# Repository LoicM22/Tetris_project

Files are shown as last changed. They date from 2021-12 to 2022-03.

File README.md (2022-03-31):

# Tetris_project

The goal of this project was to create a wireless controller to a Tetris game which is coding in Python. 
All the steps for the creation of this project are detailed on "final_notice_tetris_project.pdf".

# Details of each folder

This repository is divided in 5 parts :

  - Assembly_of_the_controller : the assembly instructions and all the drawings of the parts of the controller
  - How_to_play : details of the movements of the game in fr and eng
  - PCB : Kicad files of the PCB made for the LED of the controller
  - Prog_Rasp : The code to put in the Raspberry and the instructions
  - Prog_Arduino : The code to put in the Arduino and tests for the state machine

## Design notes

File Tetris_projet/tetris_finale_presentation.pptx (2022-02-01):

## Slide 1

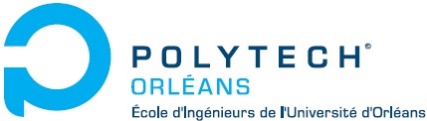
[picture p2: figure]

Project S10: Tetris project
24/01/2022

Student of Project:
MARCHAND Loïc

Tutor of Project:
WEBER Rodolphe

## Context

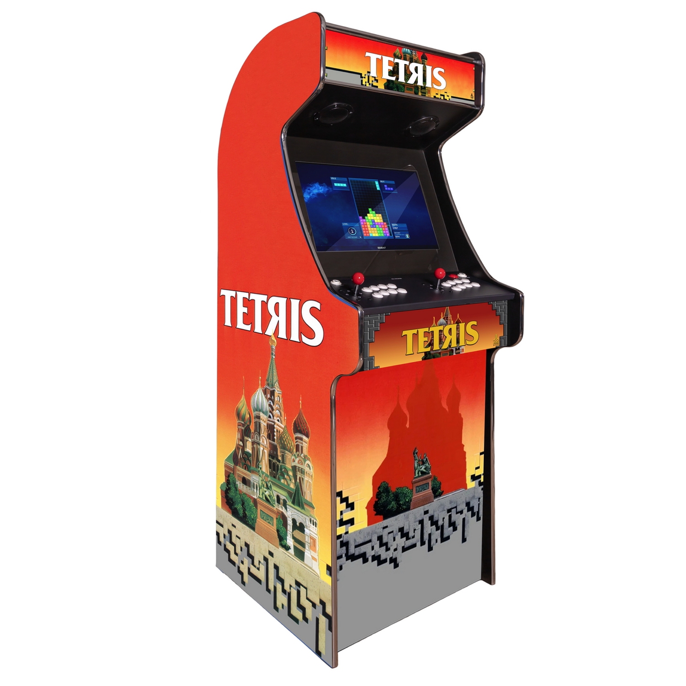
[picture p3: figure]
Borne Arcade Tetris – EZ Borne Arcade – le spécialiste de la borne arcade.
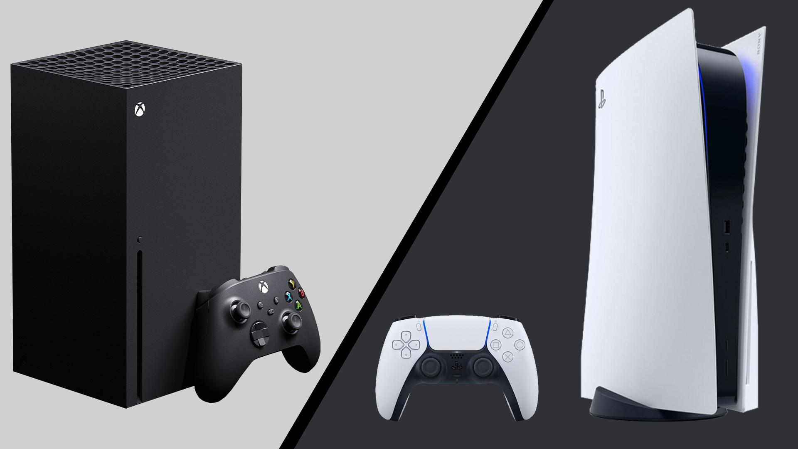
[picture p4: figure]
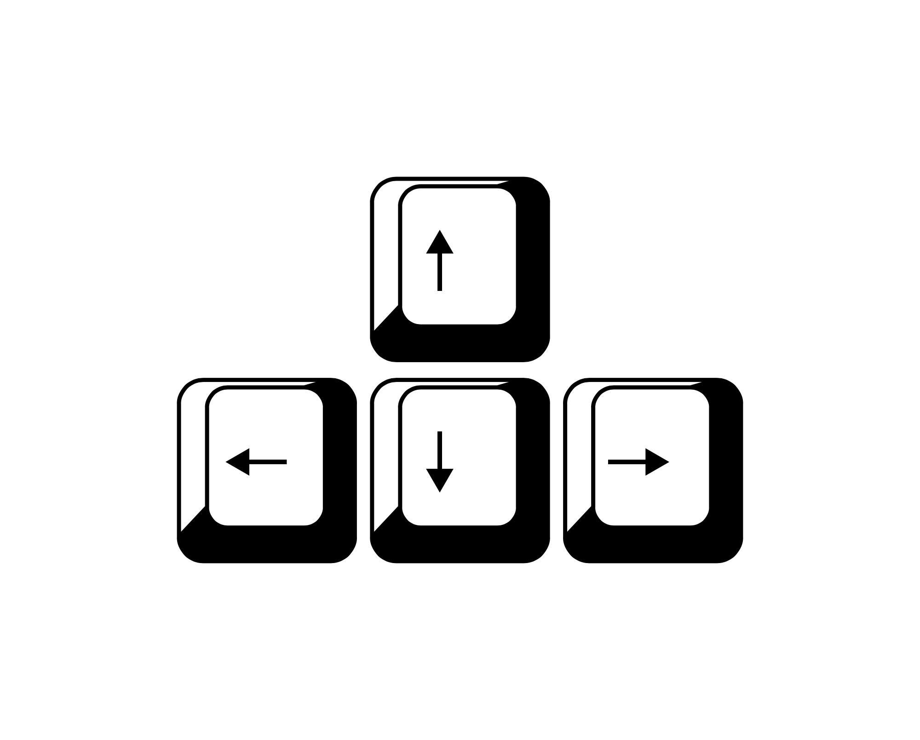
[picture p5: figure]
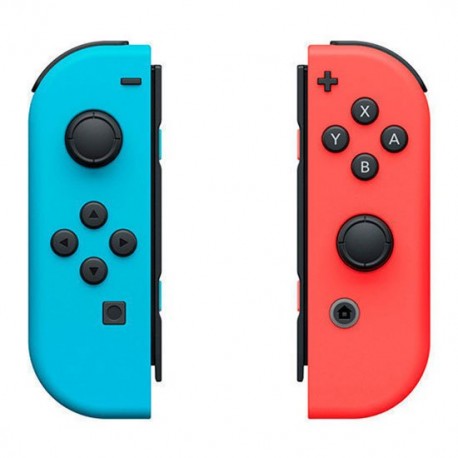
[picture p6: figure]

Loïc Marchand
5A GPSE

## Context

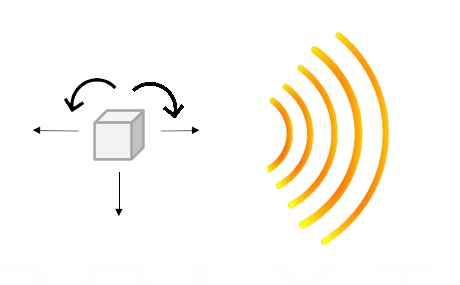
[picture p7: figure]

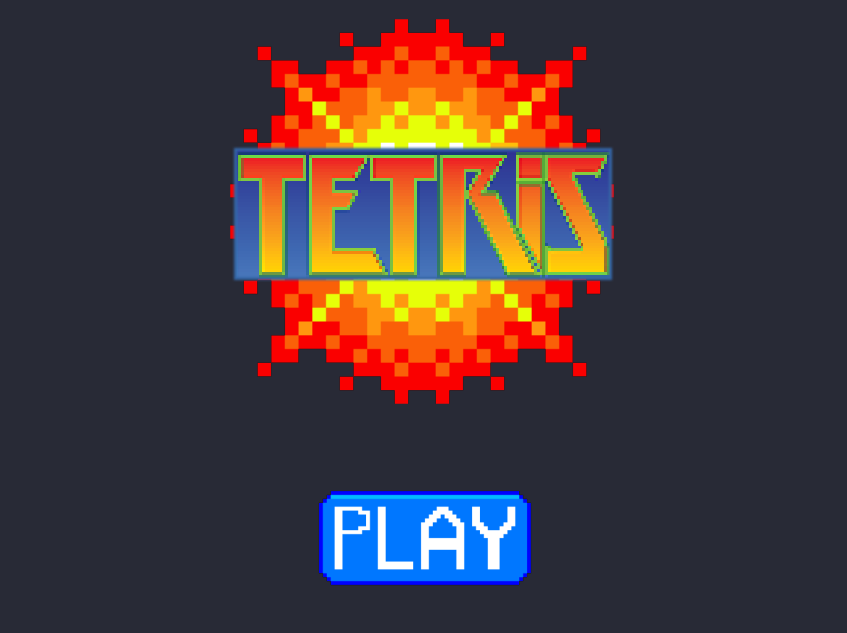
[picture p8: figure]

Loïc Marchand
5A GPSE

## Objectives

Playable by a child :
Operating time : > 1h
Operating distance : ~ 2m
Response time : < 250ms

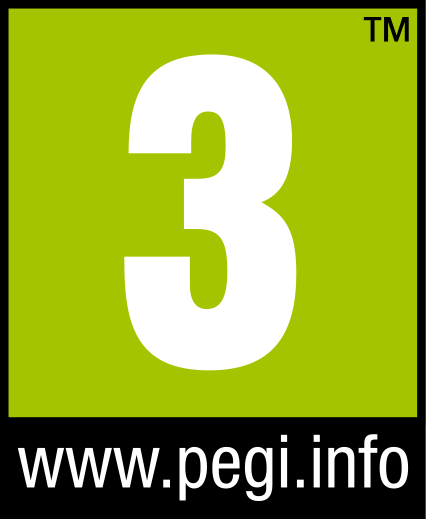
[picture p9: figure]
PEGI

Weight of the controller : < 500g
Reload time of the controller : < 30 min
Size of the controller : 7x7x7 cm
Power Supply of arcade terminal : 230V

Loïc Marchand
5A GPSE

## Global operation

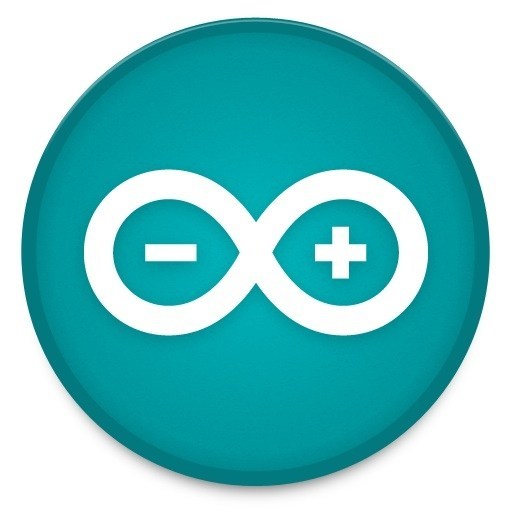
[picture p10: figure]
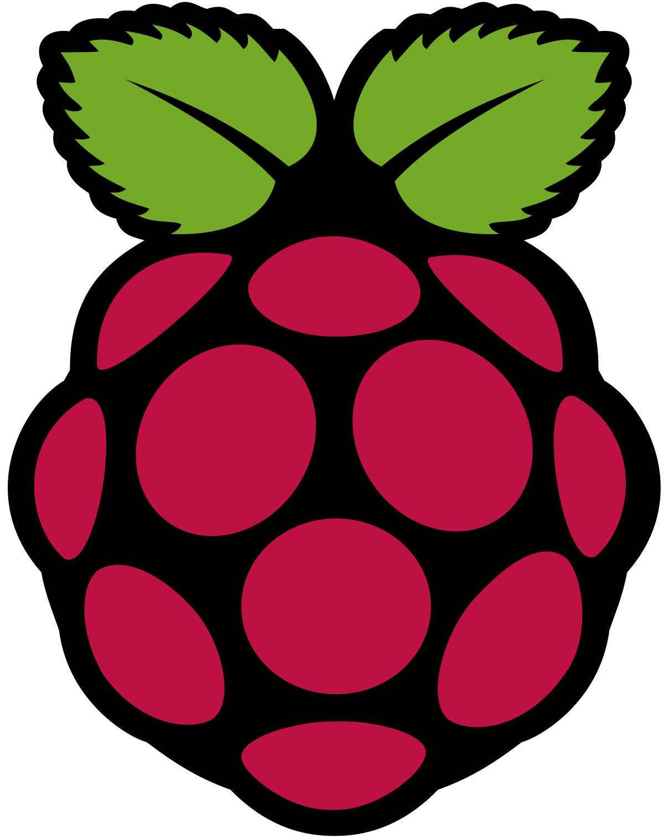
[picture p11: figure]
Raspberry Pi — Wikipédia

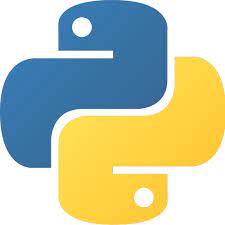
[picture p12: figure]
Pygame Logo - LogoDix

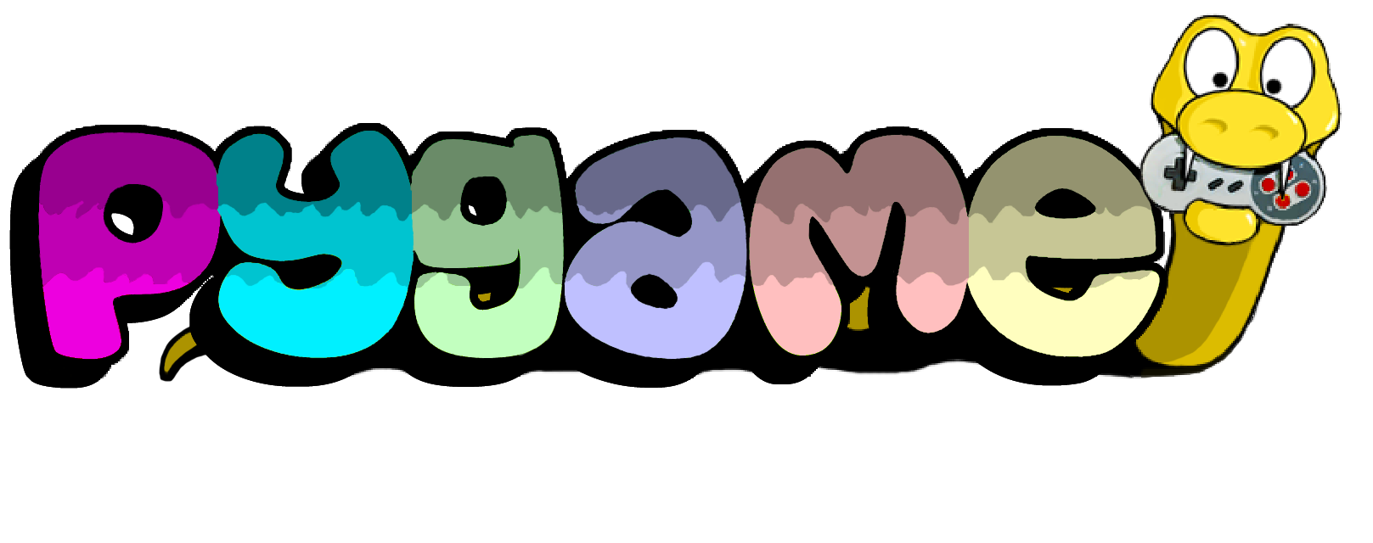
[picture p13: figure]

Arduino Nano Every
AVR ATMega 4809

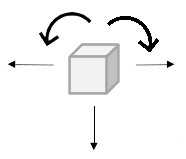
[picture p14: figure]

Serial communication : Rx / Tx

Raspberry Pi 3B+

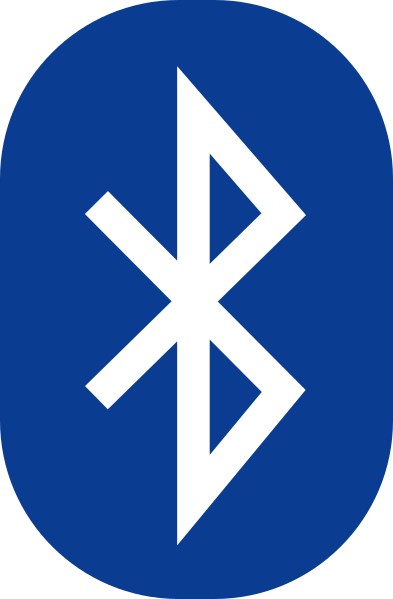
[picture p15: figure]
Fichier:Bluetooth.svg

Loïc Marchand
5A GPSE

## The controller

The design

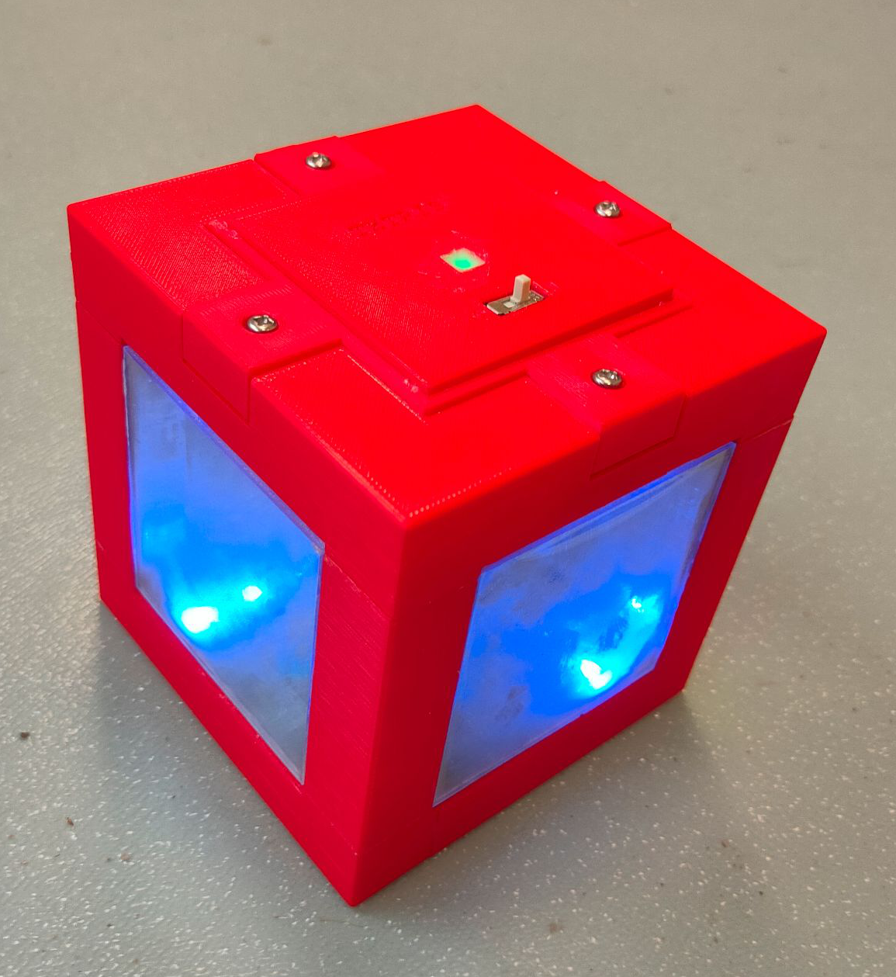
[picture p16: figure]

Size : 10 x 10 x 10 cm
Weight : 373 g
Number of LEDs : 61 LEDs

Loïc Marchand
5A GPSE

## The controller

The electronic part

LED power SJ-10060-2811
+
Power switch

Battery
9V

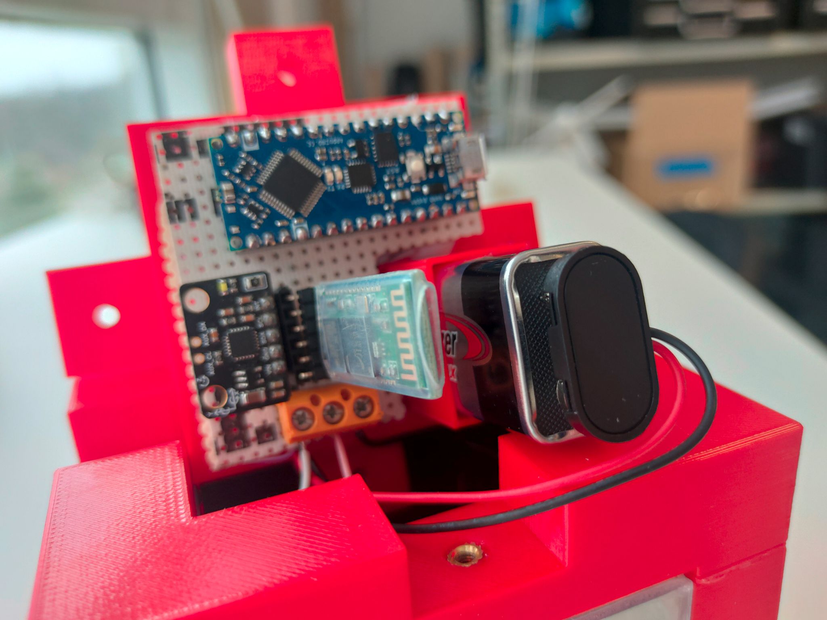
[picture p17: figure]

(3h of autonomy)

Analogic

FastLED / leds[i]

AVR ATMega4809

MPU-6050

LED strip iPixel
SJ-10060-2811

FastLED / leds[i]

I2C

Rx/Tx

HC-05

Serial

(10 meters of
operating
distance)

Loïc Marchand
5A GPSE

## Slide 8

The arcade terminal

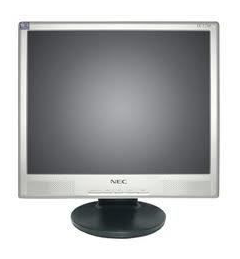
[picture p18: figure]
Nec Ecran LC17M 17&quot; 700P - LaptopService

Screen NEC lc17m (17 inches)

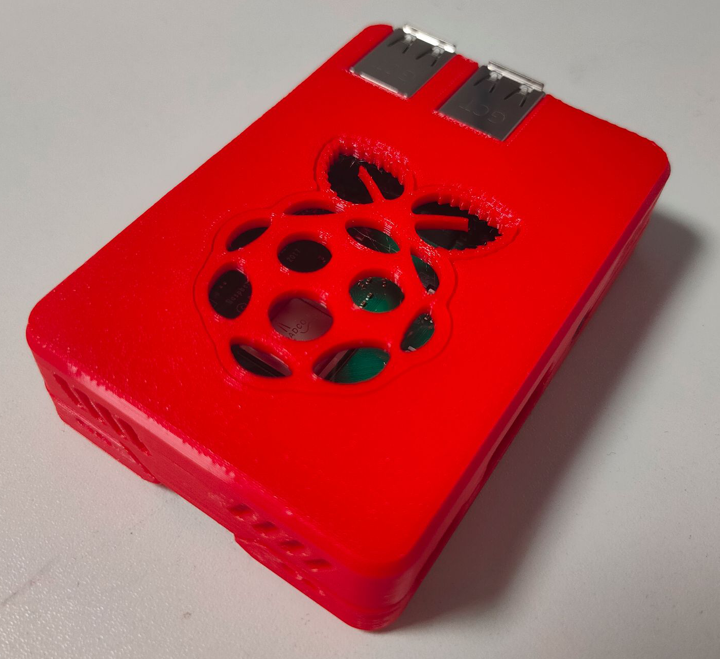
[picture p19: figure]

Raspberry Pi 3B+

Loïc Marchand
5A GPSE

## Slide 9

The arcade terminal

Raspberry part

‘s’

‘w’

‘g’

‘j’

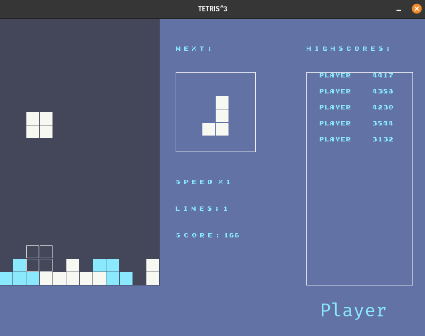
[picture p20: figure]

(Inspired by “farhan” Tetris program)

‘h’

Received by the Raspberry :

- g = b’left\r\n’
- j = b’right\r\n’
- h = b’down\r\n’
- s = b’rotleft\r\n’
- w = b’rotright\r\n’

Loïc Marchand
5A GPSE

## Skills developed

The controller | The arcade terminal
SolidWorks | Pygame : the Python library
The bluetooth of the HC-05 | The bluetooth of the Raspberry
State machine | Python
C language
Kicad

Loïc Marchand
5A GPSE

## Budget

Controller | | Arcade terminal
Components | Price | Components | Price
Arduino Nano Every | 11,35 € (RS Component) | Screen (NEC LC17m) | 89,95 € (Amazon)
HC-05 | 14,50 € (Go Tronic) | Raspberry 3B+ | 28,56 € (RS Component)
MPU6050 | 10,50 € (Go Tronic) | SD card (16Go) | 8,44 € (RS Component)
Battery 9V / 6LR61 | 3,62 € (Conrad)
LED strip (iPixel SJ-10060-2811) | 6,25 € /m (60 LEDs/m) (Alibaba)
PLA (173,09 g) | 18,20 € (filament bobbin of 750 g) (Smart Material 3D)
Power switch | 1,10 € (RS Component)
Resistances (2*330Ω/100kΩ/220kΩ) | 4 * 0,038 € (RS Component)

Time spent : 336 h

Total components : 198,88 €

Loïc Marchand
5A GPSE

## Improvements

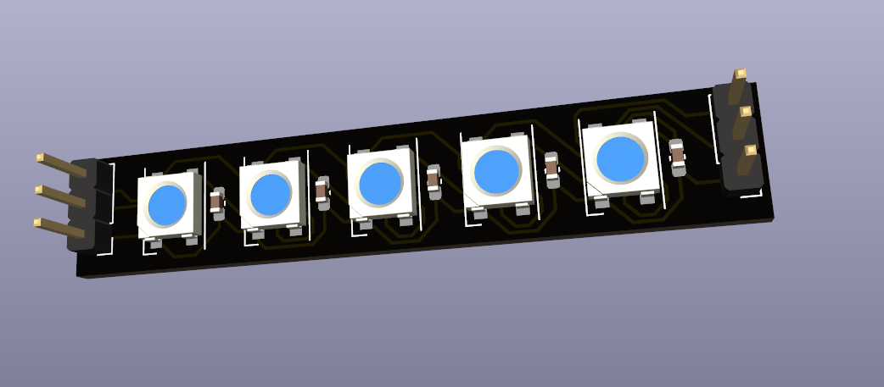
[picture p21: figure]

- Create two PCBs :
  - ~~LEDs~~
  - Controller
- Consolidate the controller to be shock resistant and waterproof
- Add another game (PacMan) with a menu to choose the game we want
- Create the box of the arcade terminal with interactive light

Loïc Marchand
5A GPSE

## Conclusion

Loïc Marchand
5A GPSE

## https://github.com/LoicM22/Tetris_project.git

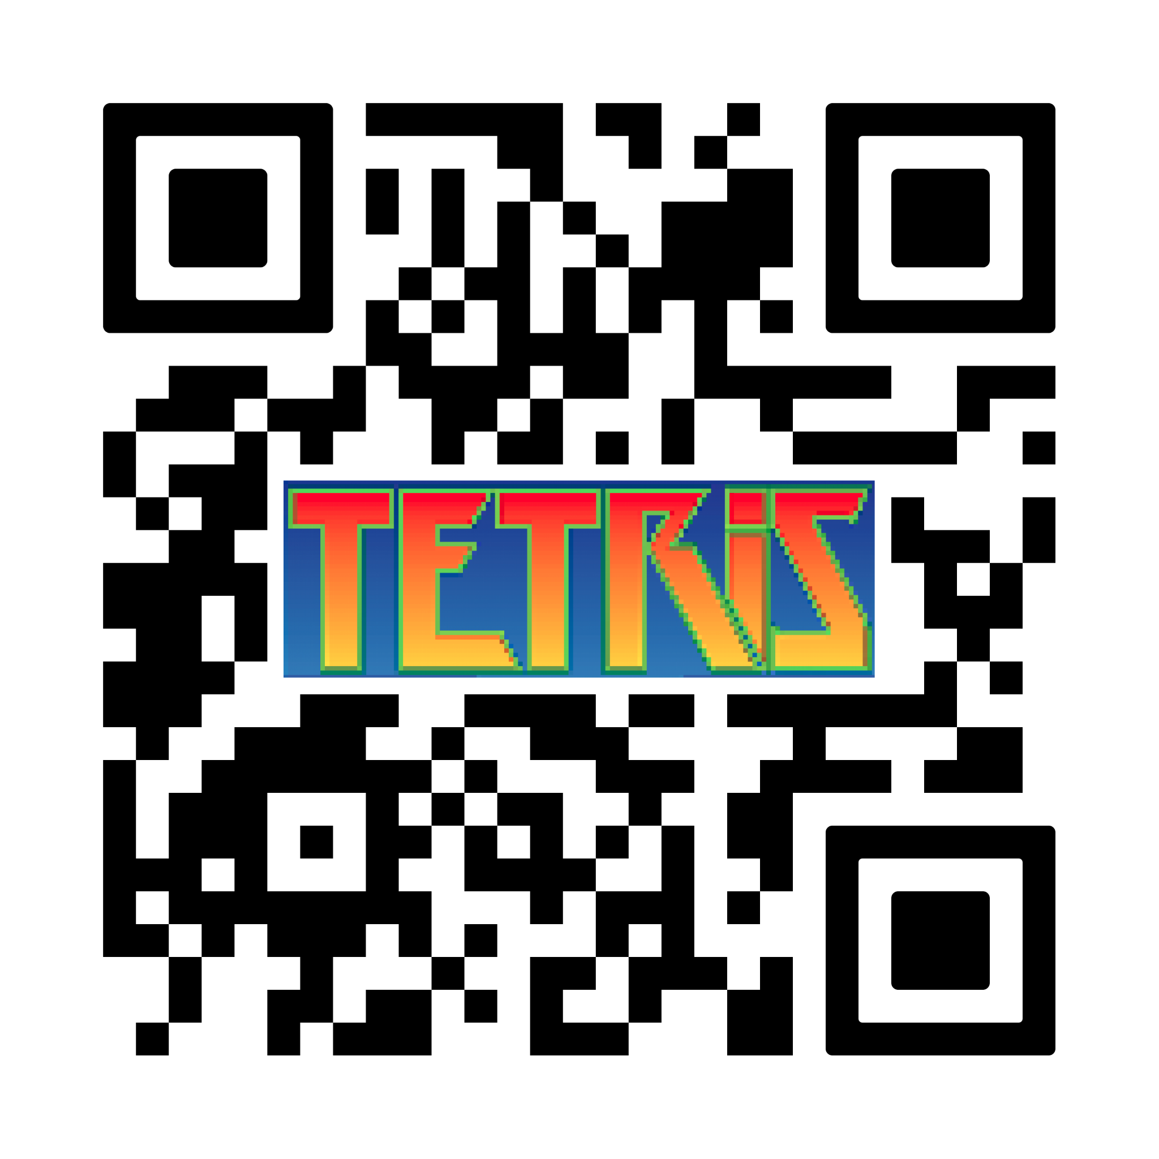
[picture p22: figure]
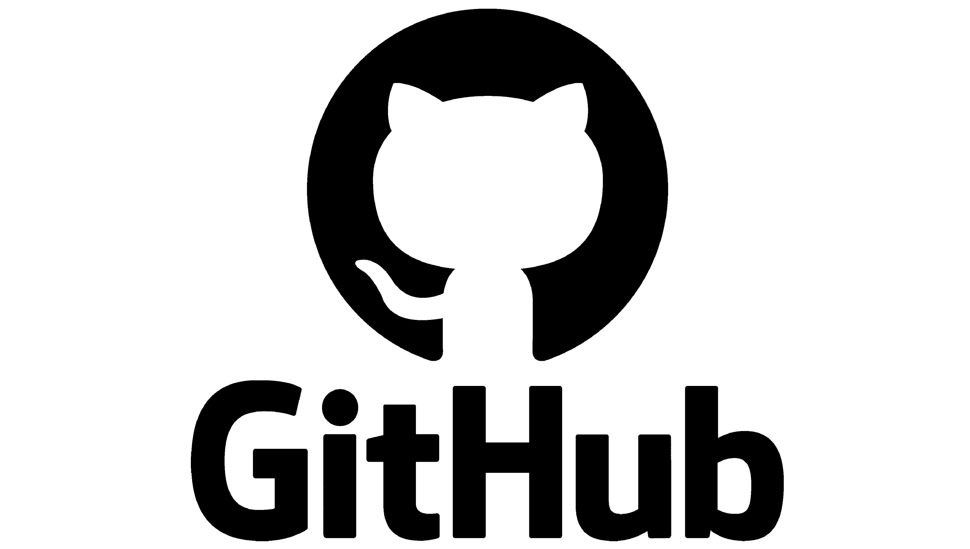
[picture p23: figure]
GitHub Logo - Marques et logos: histoire et signification | PNG

Loïc Marchand
5A GPSE

## Demonstration

Loïc Marchand
5A GPSE

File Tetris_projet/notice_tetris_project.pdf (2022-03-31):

# Notice

# Project Tetris : TETRIS³

## Tutor of the project :

Mr. WEBER Rodolphe (Polytech)

# Contents

Contents | 1
1 Abstract | 3
2 Introduction | 4
3 The controller | 8
4 The arcade terminal | 20
5 Conclusion | 25

1

Polytech Orléans | Notice | 2021 / 2022
List of Figures | 26
A Appendix of the controller | 28
B Appendix of the arcade terminal | 38
Loïc Marchand | Tetris³ | 2

# 1.Abstract

The main subject of this project is to create a new way to play a Tetris game. Indeed,

currently everybody who plays a Tetris game uses a joystick or a keyboard with arrow to

interact with the game.

So, the goal of this project is to be able to play Tetris while using a remote control

that would be inclined or moved (to the right or left) according to how we want to interact

the Tetris block.

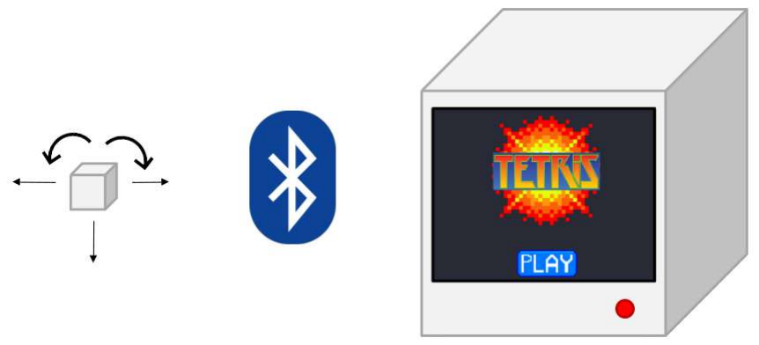
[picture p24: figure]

Figure 1.1: Diagram of the project

# 2.Introduction

## 2.1 Context

Nowadays, the world of gaming is constantly evolving. More and more games are im-

proved to become more like the real life (haptic devices, photorealism, ...).

Nevertheless, the old games like Pac Man, Space Invaders or Tetris attract always the

generation which has grow up.

To make new gamers want to play the old games, some people create a new version of

these games. The gameplay will never change a lot but sometimes the look or maybe a

new mode.

It is with this idea that this project has been designed.

Indeed, with Tetris³, the game doesn’t change but it’s a new way to play to this famous

game.

More technically, this new way is resumed by the control of Tetris with a little cube

connected with Bluetooth to a Raspberry linked to a screen and play a Tetris game.

The little cube is like a wiimote for the Nintendo console. To move the Tetris block on

the screen on the right, the little cube has to be moved on the right too (it’s the same

way with all the other movements).

## 2.2 The project’s goals

In order to define the project and to see more clearly the final objective, a global diagram

has been established :

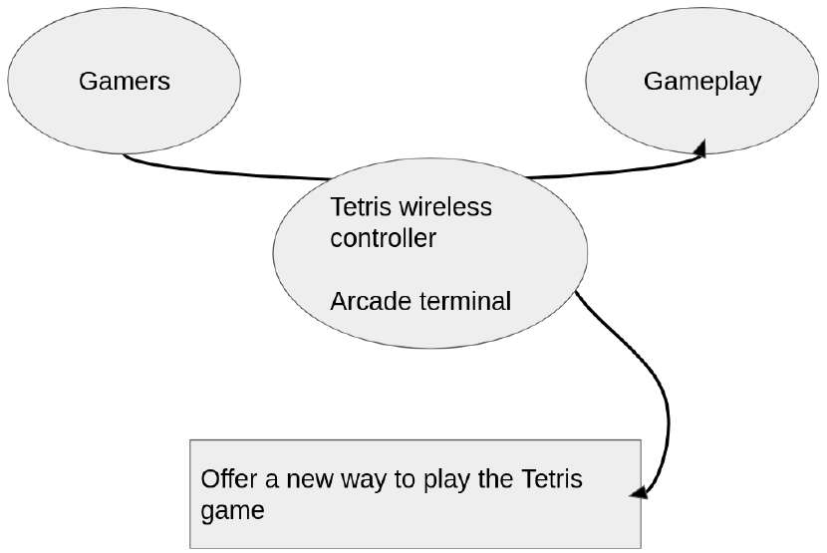
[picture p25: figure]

Figure 2.1: Header beast diagram

After defined the bases of the project, the use functions have to be listed with their

constraints :

Id | Functions | Details | Criteria | Solutions
FP1 | User can play Tetris
FP1.1 | | A user-friendly interface | Usable by a 3 years old chil-dren

FP2 | Having a cube that allows the Tetris to be con-trolled remotely by movements
FP2.1 | | Wireless control cube | Lenght : 2 m | Bluetooth
FP2.2 | | Rechargeable | Time of use : 1h Recharge time : 30min
FP2.3 | | Easy to use | Usable by a 3 years old chil-dren
FP2.4 | | Be fall resistant | Height : 2m
FP2.5 | | Visually attrac-tive | | LED and mirrors
FP3 | Play Tetris on an arcade termi-nal
FP3.1 | | Good quality | | Screen : 17 inches
FP3.2 | | Interact with the game | Lighting effect

FC1 | Be intuitive | Simple control
FC2 | Python program must be flexible | Possibility to put all of the instructions we want
FC3 | Arcade machine works with main power | 230V
FC4 | Good quality of video an sounds | Screen and speakers
FC5 | Be ergonomic | Weight < 500g

The global operation of the project looks like the following diagram :


Figure 2.2: Diagram of the global operation

To resume, the goal of the project is to realise a wireless controller which permit to

control a Tetris on an arcade terminal with the movement of the gamer.

So, in the first instance, the creation and the programming of the controller will be

exposed.

After that, the design of the arcade terminal will be explain.

# 3.The controller

## 3.1 The design

### 3.1.1 The modelling

So, the appearance of the controller is a cube of 10x10x10cm (indeed, the 7x7x7cm wasn’t

enough to put all the light system and the electronic part inside the cube).


Figure 3.1: Photo of the controller

The cube was printed with 3D printer and is composed by PLA (173,09g). It is divided

in nine parts (two for the base of the cube, four for the poles and three for the roof).


### 3.1.2 The wire management

All of these pieces were made with SolidWorks (CAO software) :

Figure 3.2: Model of the tops of the controller

Figure 3.3: Model of the posts of the controller


Figure 3.4: Model of the bases of the controller

The assembly instructions and the drawings of all the pieces of the controller are

detailed on the appendix A.

### 3.1.3 The light effect

The light effect on each face is an infinite effect.

The necessary equipment to create this infinite effect is one mirror, one half reflecting

glass and obviously some LEDs. If these LEDs are positioned between the mirror and the

half reflect, all the light will be reflected on the mirror but that will not be the same case

for the half reflect glass. It let pass only the half light and reflect the other half and it’s

this phenomenon which create the infinite effect.

## 3.2 The electronic part

Figure 3.5: Photo of the electronic part

The electronic part inside the cube is divided in four parts. All of these parts are con-

trolled by an Arduino Nano Every which is composed by an AVR ATMega 4809 (the

microcontroller). This type of board was chosen for its simplicity of programming.


Figure 3.6: Schematic of the electronic part

A more detailed schematic of the electronic part can be found in appendix A.10.

### 3.2.1 The LED strip


Figure 3.7: Schematic of the LED strip part

In this part, there is the LED strip (composed by 60 RGB LEDs), one resistance of

330ohm and the Arduino. The LED strip has 3 pins, one for the 5V, one for the ground

and a last one to program the LED strip. Indeed, this LED strip is addressable so it’s

possible to choose which LED will turn on and with which color by using FastLED (it’s

an Arduino librairy which works with this LED strip). To not damage the LED strip,

one resistant must be connect between the pin of the Arduino and the pin which permit

to program the LED strip.

To create a movement of rotation with the LED on every face of the cube, it’s neces-

sarily to make a loop between 12 LEDs and at each "i" loop, the LED "i-1" is turned off

and the LED "i" is turned on. When the loop was made 12 times, the patern is restarted.

### 3.2.2 The battery


Figure 3.8: Schematic of the battery part

The controller (so the Arduino) is powered by a 9V battery. To find out how much

battery is left before the Arduino is under powered, it’s useful to create a tension divider

bridge and connect it to one analogic pin to the Arduino. Indeed, the analogic pins of the

Arduino Nano Every can support only 5V but no more.


Figure 3.9: Schematic of the tension dividing bridge

After that, with a program which calculates the pourcentage of the battery on the

Arduino and with the use of one new RGB LED, the user will know how much time the

controller will continue to be powered. This LED will be blue if the pourcentage of the

battery is between 100% and 80%, green between 80% and 60%, yellow between 60% and

40%, orange between 40% and 20%, and finally red under 20%.

### 3.2.3 The MPU6050


Figure 3.10: Schematic of the MPU6050 part

The MPU6050 is a component with an accelerometer 3 axis and a gyroscope 3 axis.

The accelerometer will be reserved for the translation movements of the tetris block

and the gyroscope for the rotation.

But, without adjustment, the accelerometer and the gyroscope can’t be used.

### 3.2.3.1 The accelerometer


Figure 3.11: Graphic of the evolution of acceleration on Y axis

In fact, for example with the accelerometer with the Y axis on the figure 3.9, the blue

curve represents the variation of the value of the Y axis sensor for the acceleration during

175 seconds. It’s a test made with a Python program to observe how the acceleration

evolve during a movement. When the sensor is moved on the direction of positive Y there

is a rise in value and immediately after a fall until reaching the opposite value and the

returning to a value close to zero. This phenomenon is due to the compensation of the

acceleration.

Indeed, when something accelerate and stop very quickly, an opposite acceleration,

due to the compensation, is detected. That create a problem if we want to distinguish a

movement (go to right for example) and its opposite (go to left).

To detect the right movement and to prevent the acceleration compensation, the tech-

nique adopted is the creation of a state machine to analyse every possibility of our signal

and assign the appropriate move when it’s relevant.


Figure 3.12: Schematic of the state machine for the accelerometer

The numbers in red represent all the different states in which the system can be. Sp

and Sn are two thresholds which are been chosen after some tests with the different values

of the accelerometer, Sp is the positive threshold and Sn is the negative one.

To explain this state machine, as long as the value of the accelerometer doesn’t surpass

Sp or Sn, there isn’t movement detected. As soon as the threshold is exceeded by the value, the instruction of the movement is sent at the state 1 or 3 (for example, with the

X axis, when Sp is exceeded the program sends "right", and "left" if it’s Sn). As long as

the value is superior (for Sp) or lower (for Sn), there isn’t movement sends.

The state 2 and 4 are made to avoid the acceleration compensation. Indeed, for

positive value, while it doesn’t surpass Sn, the program stays in the state 2 and send

nothing. That is the same with negative value, while it doesn’t be lower than Sp the

program stays in the state 4. The result is observable with the orange curve one the

Figure 3.9.

In this project, this state machine will be mainly used for the "left" and "right"

movements (on the X axis) and for the "down" movement (on the Z axis).

### 3.2.3.2 The gyroscope

Another problem appears with the gyroscope.


Figure 3.13: Graphic of the evolution of gyroscope on X axis

Indeed, when the controller is turned in one direction (left or right), everytime the

program on the Arduino makes a loop and as long as the position of the controller is

not changed, an instruction of movement is sent (blue curve on Figure 3.11). To have a

playable game, the gyroscope must send the movement only after a change of the position

of the cube.


Figure 3.14: Schematic of the state machine for the gyroscope

In this state machine, four thresholds have been introduced, two for the positive values

and two for the negative values (one for a low threshold and one for a high threshold).

For example with the positive part, as long as the value of the gyroscope doesn’t

surpass Shp (the positive high threshold), nothing will be send and the program stay

on state 0. At the moment of the value exceeds Shp the program pass on state 1, the

instruction of the movement of rotation is sent (here "rotright" for the right rotation)

and directly after the program changes on state 2. While the value is higher than Sbp,

nothing changes and the program stays on state 2. As soon as the signal is lower than

Sbp, the program changes on state 0 only and nothing is sent.

The effect of this state machine is observable one the figure 3.11 with the orange curve.

In the graphic, the Shp is equal to 12000, Shn is equal to -12000, Sbp is equal to 5000 and

Sbn is equal to -5000. These different values are chosen to have a good playing experience

without interfere with the acceleration information as far as possible.

### 3.2.4 The Bluetooth


Figure 3.15: Schematic of the blutooth part

The bluetooth deserves to link the controller (here the Arduino) to send the instruction

of movement with the arcade terminal (here the Raspberry). Every information is sent

with a serial communication. In this project, the information sent by the Arduino are

"left", "right", "down", "rotright" and "rotleft".

The bluetooth is made with a HC-05 which is linked to the Rx/Tx pins of the Arduino.

It’s a good bluetooth module in the case of this project because it’s easy to use, the

consumption of the battery isn’t so high (80mAh), the sending data time is closed to the

real time and the operating is higher than 10 meters.

# 4.The arcade terminal

This part deals with the creation of the arcade terminal. The arcade terminal is composed

by a screen and a Raspberry Pi 3b+.


Figure 4.1: Components of the arcade terminal

As we can see on the figure 4.1, a keyboard and a computer mouse are still necessary

to navigate and use two commands to play Tetris with the controller (the commands are

on the Appendix B.1).

## 4.1 The Tetris game

The Tetris game is a Python program inspired by the Tetris program of farhan on GitHub.

The game is divided in 3 parts.

There is the opening screen :


Figure 4.2: Opening screen of the game

After press the ENTER key, the game is on and a second screen replaces the first one.

It’s the screen where the user plays the game :


Figure 4.3: Screen of the playable game

When the game is over, an new screen appears :


Figure 4.4: Game over screen

To start a new game, the ENTER key has to be pressed again.

This Python program has been chosen because of its simplicity of programming. In

fact, all the game is developed with Pygame library. This library deserves to program

some games (not only Tetris) on Python and it’s a very intuitive library. Thanks to

this library, it’s easy to change the music, the sound and the color of the game (blocks,

interface), the opening and the game over screen, the speed of the game and the score.

The game launch and the bluetooth connection between the controller and the rasp-

berry aren’t automatic, so a keyboard is indispensable to write the appropriate line of

code on the terminal before playing.

## 4.2 The controls

After customize the aspect of the game, the last thing to do is to link the information

send by the Arduino with the commands of the game.

When the Arduino sends an information, the Raspberry receives the following data :

Then, it’s necessary to choose which letter will be associated with which movement.

Figure 4.5: Letters associate with movement

After chosen the letters, to interact on the game with the controller, a second Python

program must be written. This second program will imitate the press of one key on

the keyboard. For example, when the user go right with the controller, the raspberry

will associate the data it receives with the press of the ’j’ key of the keyboard. It will

run during the game in the background and it will begin in the same time the game is

launched.

The Pygame library has always some event which recognize what letter is pressed on

the keyboard. With this functionality, the project could be changed to be adapted to

other old agames (PacMan for example because this game has some simple movements

too).


Figure 4.6: Movements of the game

To make understanding of the controls of the game more intuitive, a document which

specifies all the possible movements of the game is made.

Due to lack of time, the aspect of the arcade terminal isn’t made.

# 5.Conclusion

## 5.1 General conclusion

This project was divided principally in two parts. One part about the creation of a

bluetooth controller and a second part for the assembly of the arcade terminal. For the

first part, even if the gameplay isn’t perfect with the use of the state machines, the criteria

are mostly respected. Maybe the use of the interruption to send just at the right time

the information could be a good option. For the second part, all the technical part is

operational, just the aspect of it isn’t here. For the aspect, it may be interesting to add

some LED which light up at the same time of a particular action on the game.

## 5.2 Personal conclusion

Personally, this project was a very instructive project in terms of technical skills and

project management.

With this project, I have developed my skills on programming with the comprehension

of the Tetris program to adapt it with the project (the colors of Polytech school on

the blocks for example). I discovered the use of the state machine with the different

sensors. By modelling the cube, I learned a lot of things with the use of SolidWorks. The

programming of the Arduino improves my skill on C language and the use of the bluetooth

gives me a better understanding about the communication between 2 electronic boards

(here the Arduino and the Raspberry).

In terms of project management, I upgraded my skills about time and tasks manage-

ment. Indeed, being alone on this project gives me a global vision of each role that an

engineer can have.

# List of Figures

1.1 Diagram of the project | | 3
2.1 Header beast diagram | | 5
2.2 Diagram of the global operation | | 7
3.1 Photo of the controller | | 8
3.2 Model of the tops of the controller | | 9
3.3 Model of the posts of the controller | | 9
3.4 Model of the bases of the controller | 10
3.5 Photo of the electronic part | 11
3.6 Schematic of the electronic part | 11
3.7 Schematic of the LED strip part | 12
3.8 Schematic of the battery part | 13
3.9 Schematic of the tension dividing bridge | 14
3.10 Schematic of the MPU6050 part | 15
3.11 Graphic of the evolution of acceleration on Y axis | 15
3.12 Schematic of the state machine for the accelerometer | 16
3.13 Graphic of the evolution of gyroscope on X axis | 17
3.14 Schematic of the state machine for the gyroscope | 18
3.15 Schematic of the blutooth part | 19
4.1 Components of the arcade terminal | 20
4.2 Opening screen of the game | 21
4.3 Screen of the playable game | 21
4.4 Game over screen | 22
4.5 Letters associate with movement | 23

26

4.6 Movements of the game | 24

# A.Appendix of the controller

## A.1 Assembly instructions


28

## A.2 Drawing of base_1

## A.3 Drawing of base_2

## A.4 Drawing of poteau1

## A.5 Drawing of poteau3

## A.6 Drawing of poteaux24

## A.7 Drawing of toit1

## A.8 Drawing of toit2

## A.9 Drawing of toit3


## A.10 Detailed schematic of the electronic part


# B.Appendix of the arcade terminal

B.1 | Command to launch the game on the Raspberry
B.1.1 | To connect to the HC-05

Turn on the controller

sudo rfcomm connect hci0 98:D3:91:FD:E6:9D 1

(XX:XX:XX:XX:XX:XX code depends on your stuff)

B.1.2 To run the game

cd tetris_bluetooth

run game.py (if it doesn’t work, use : python3 game.py)

## B.2 Github of the project

https://github.com/LoicM22/Tetris_project.git

38

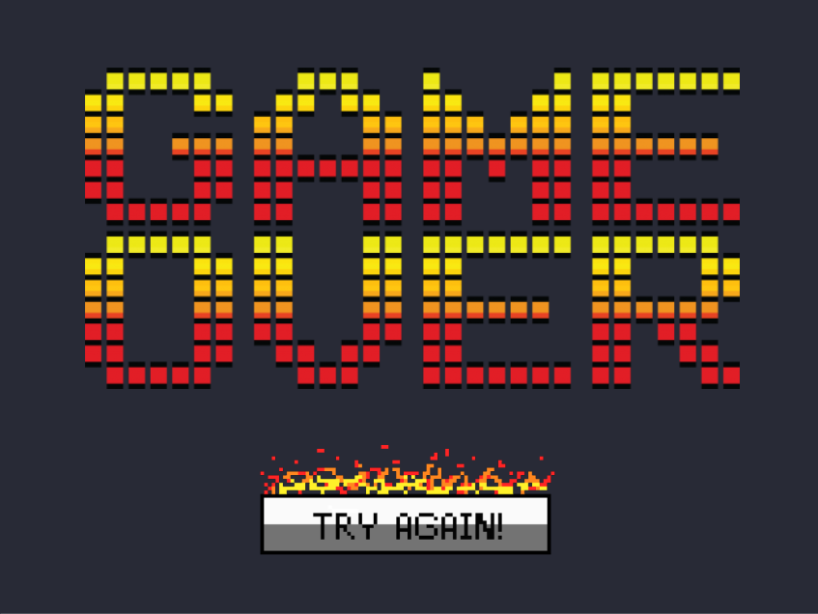
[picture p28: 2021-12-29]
Tetris_projet/Prog_Rasp/tetris_bluetooth/go_screen.png

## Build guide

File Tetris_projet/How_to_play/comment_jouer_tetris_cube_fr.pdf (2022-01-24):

# COMMENT JOUER ?

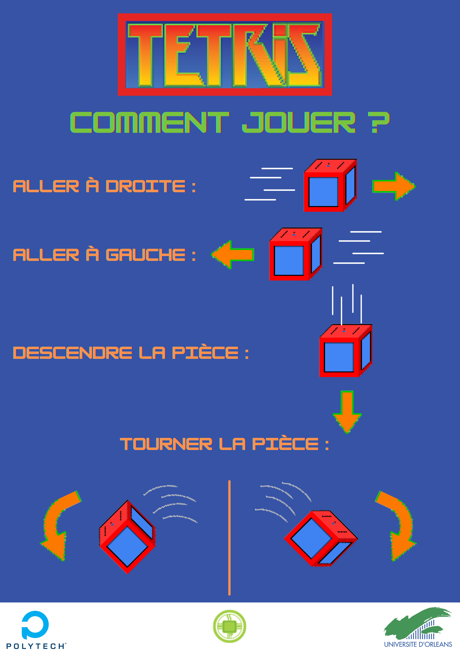
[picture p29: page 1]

TOURNER LA PIÈCE :

ALLER À DROITE :

ALLER À GAUCHE :

DESCENDRE LA PIÈCE :

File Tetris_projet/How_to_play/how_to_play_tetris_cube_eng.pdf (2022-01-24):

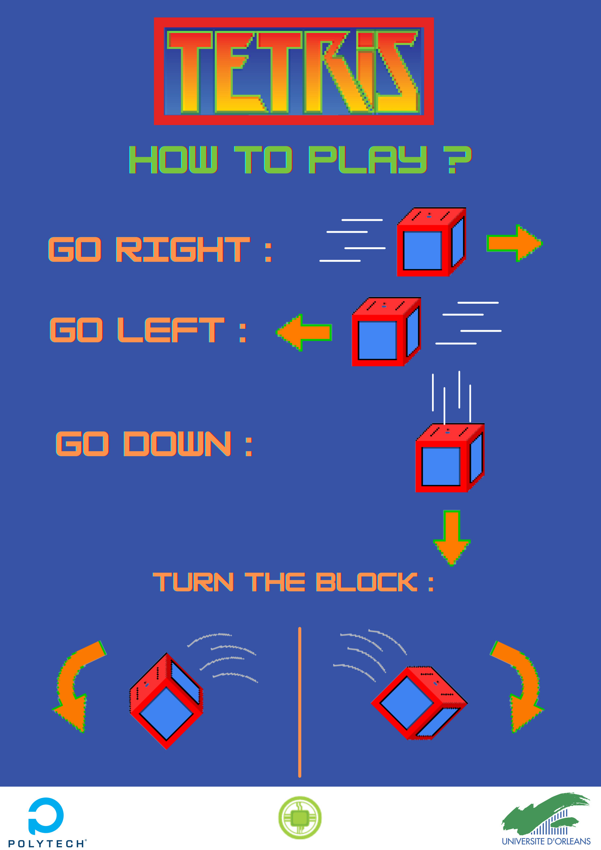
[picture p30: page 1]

TURN THE BLOCK :

HOW TO PLAY ?

GO RIGHT :

GO LEFT :

GO DOWN :

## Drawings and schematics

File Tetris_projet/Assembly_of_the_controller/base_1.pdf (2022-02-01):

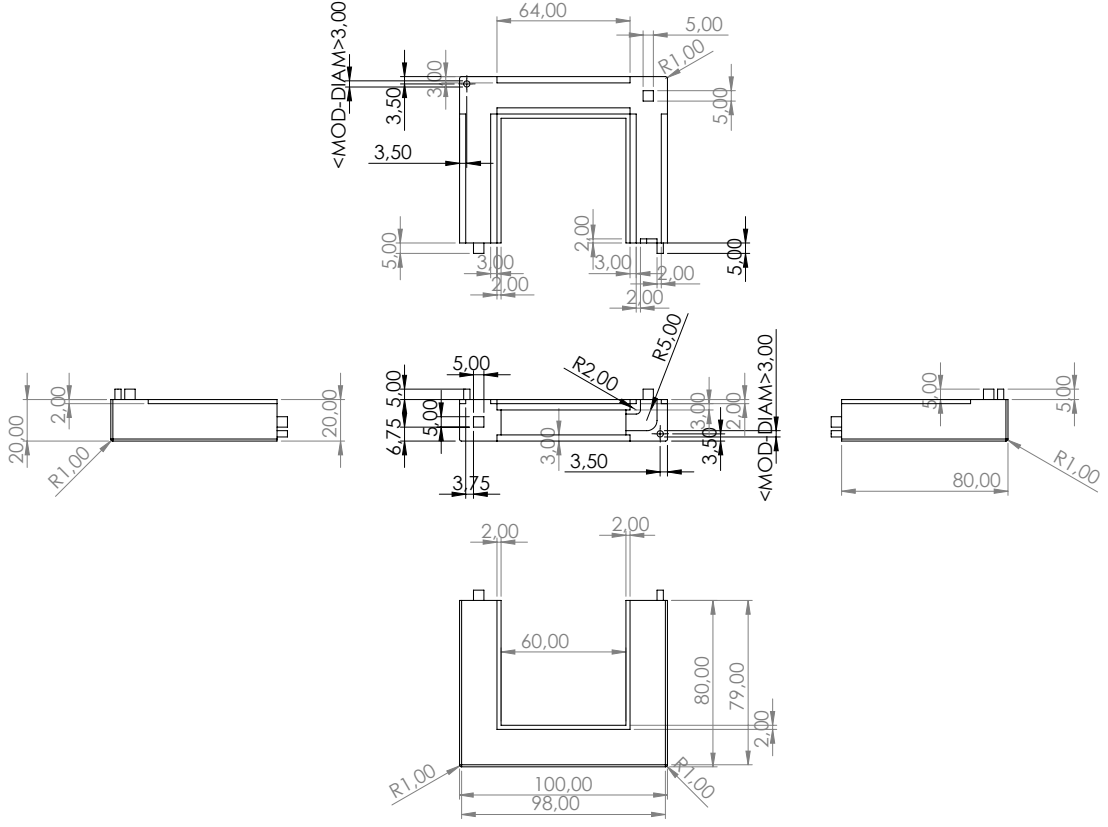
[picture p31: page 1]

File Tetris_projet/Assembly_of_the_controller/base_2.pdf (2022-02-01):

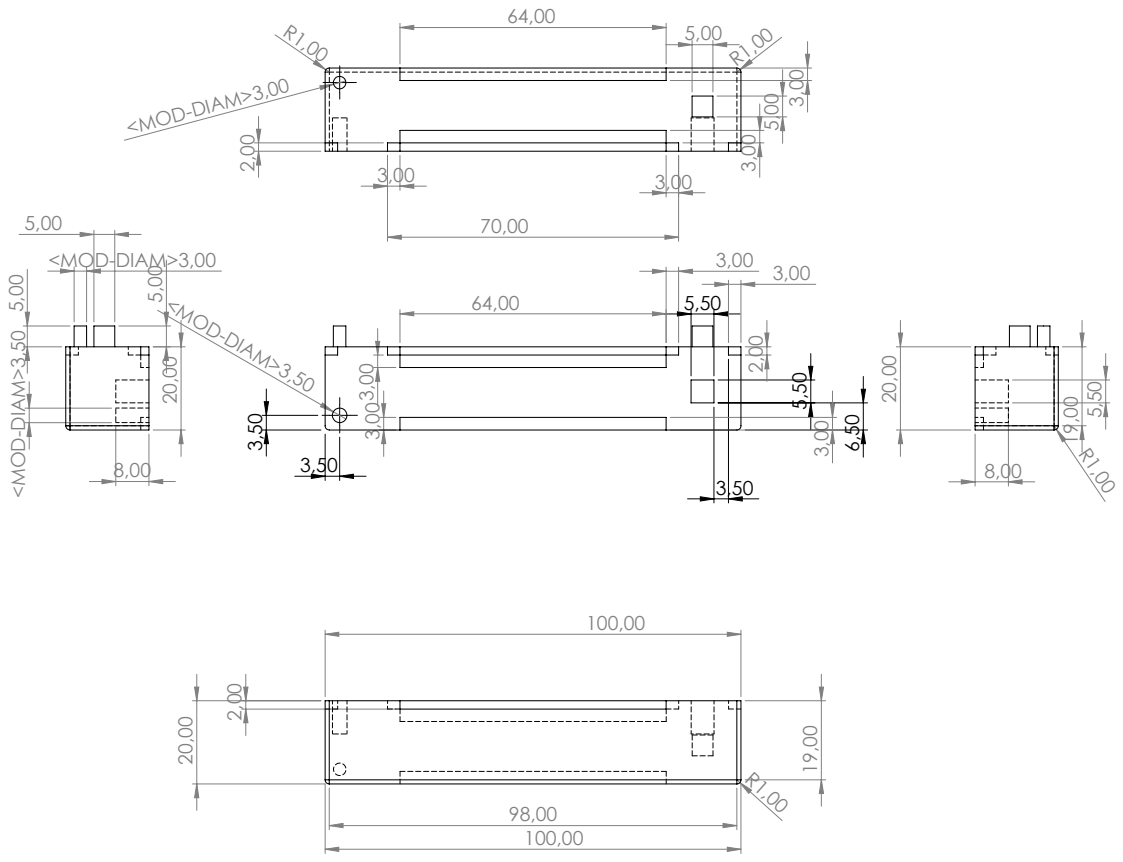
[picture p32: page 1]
64,00 R1,00 <MOD-DIAM>3,00 2,00 20,00

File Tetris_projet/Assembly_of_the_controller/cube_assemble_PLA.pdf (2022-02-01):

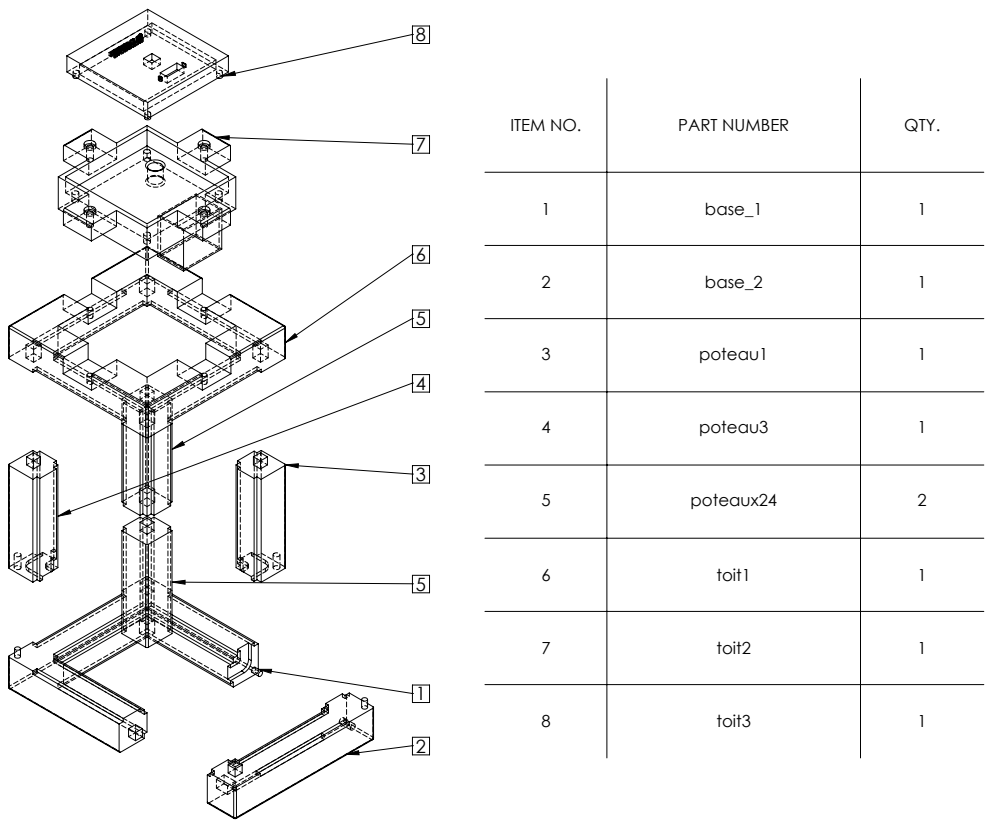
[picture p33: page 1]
ITEM NO.; PART NUMBER; QTY.

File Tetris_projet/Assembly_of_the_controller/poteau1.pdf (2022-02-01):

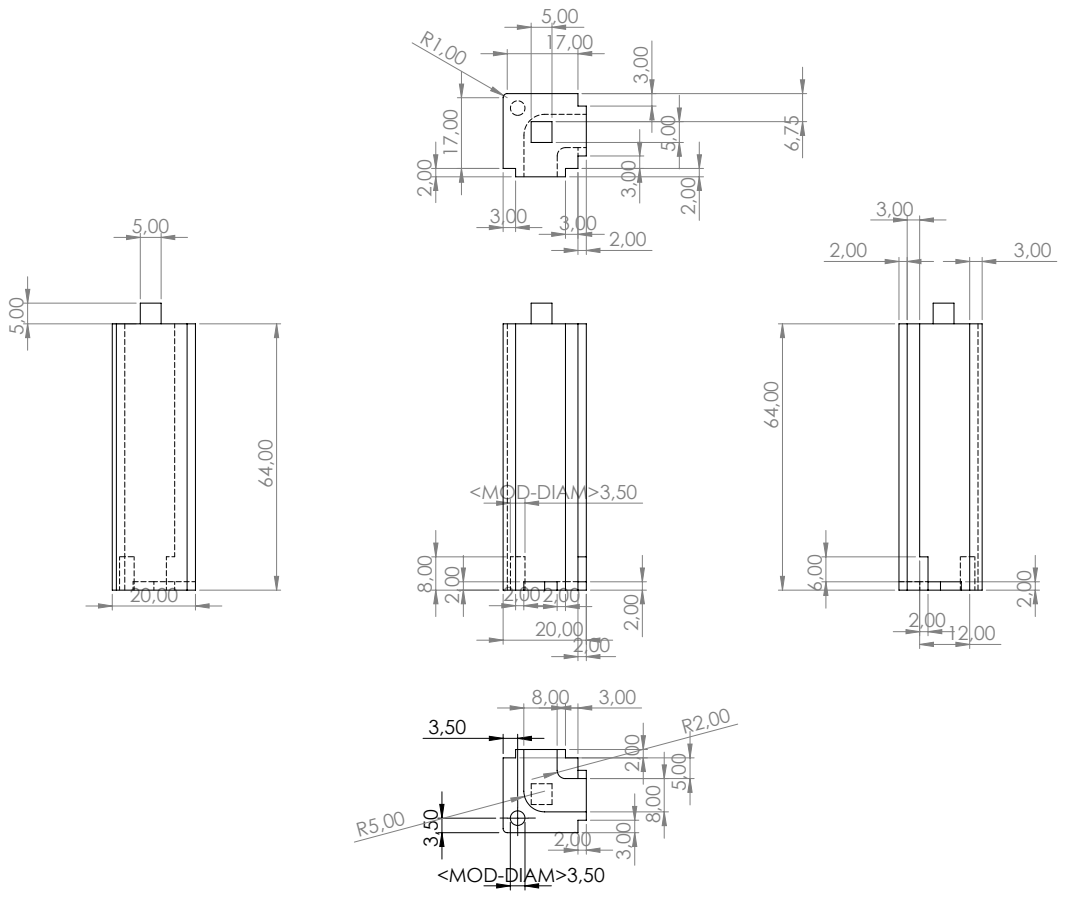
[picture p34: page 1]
<MOD-DIAM>3,50 3,50

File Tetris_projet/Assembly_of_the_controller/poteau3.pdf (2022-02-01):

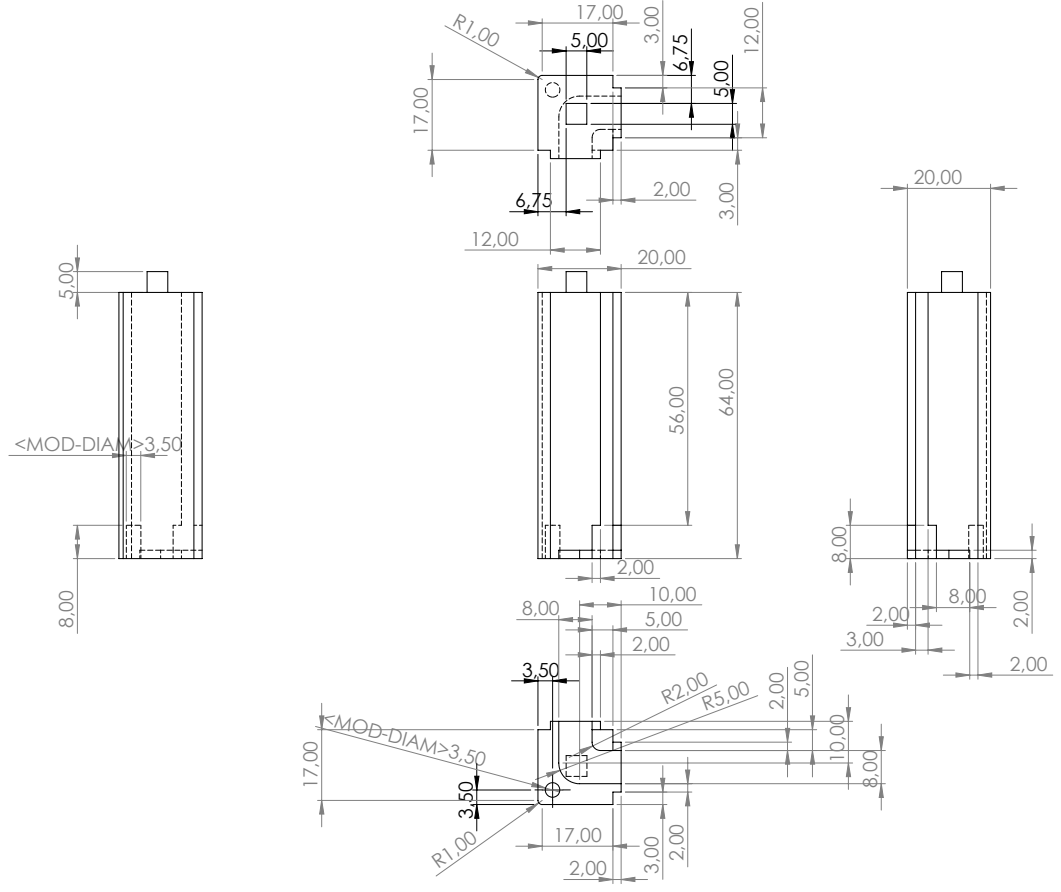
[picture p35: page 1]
<MOD-DIAM>3,50 8,00 5,00

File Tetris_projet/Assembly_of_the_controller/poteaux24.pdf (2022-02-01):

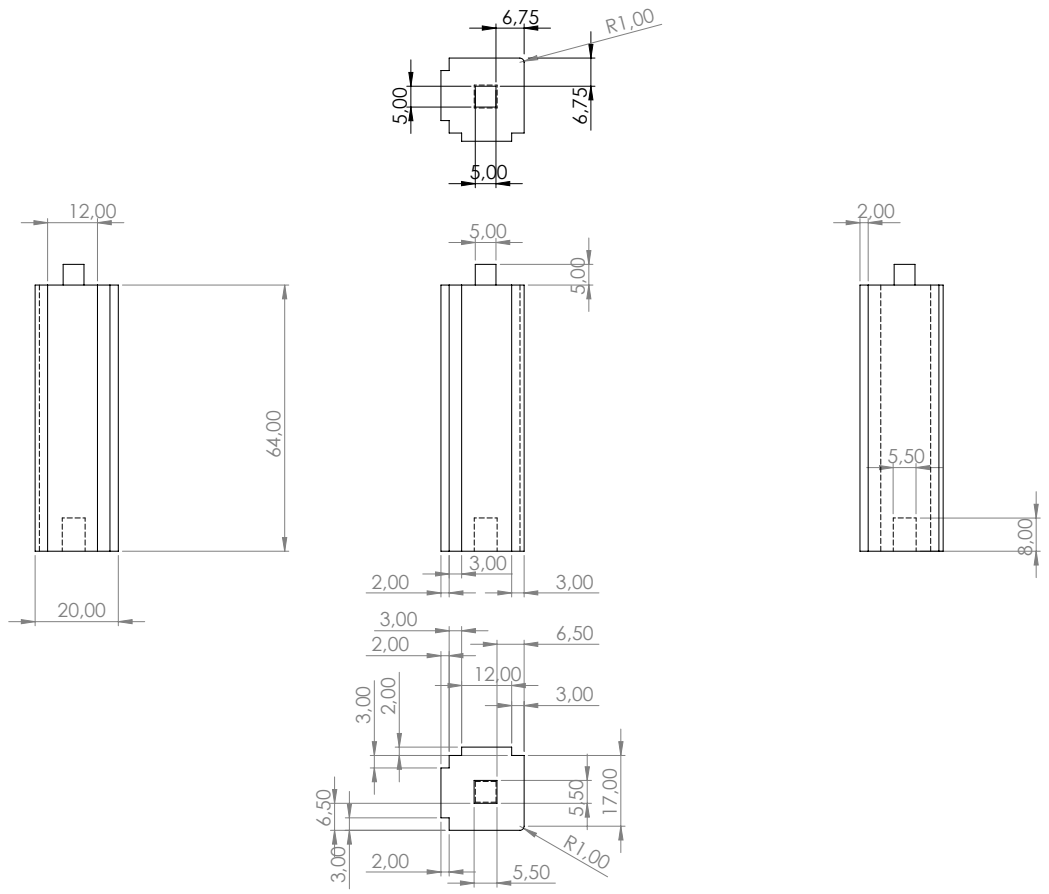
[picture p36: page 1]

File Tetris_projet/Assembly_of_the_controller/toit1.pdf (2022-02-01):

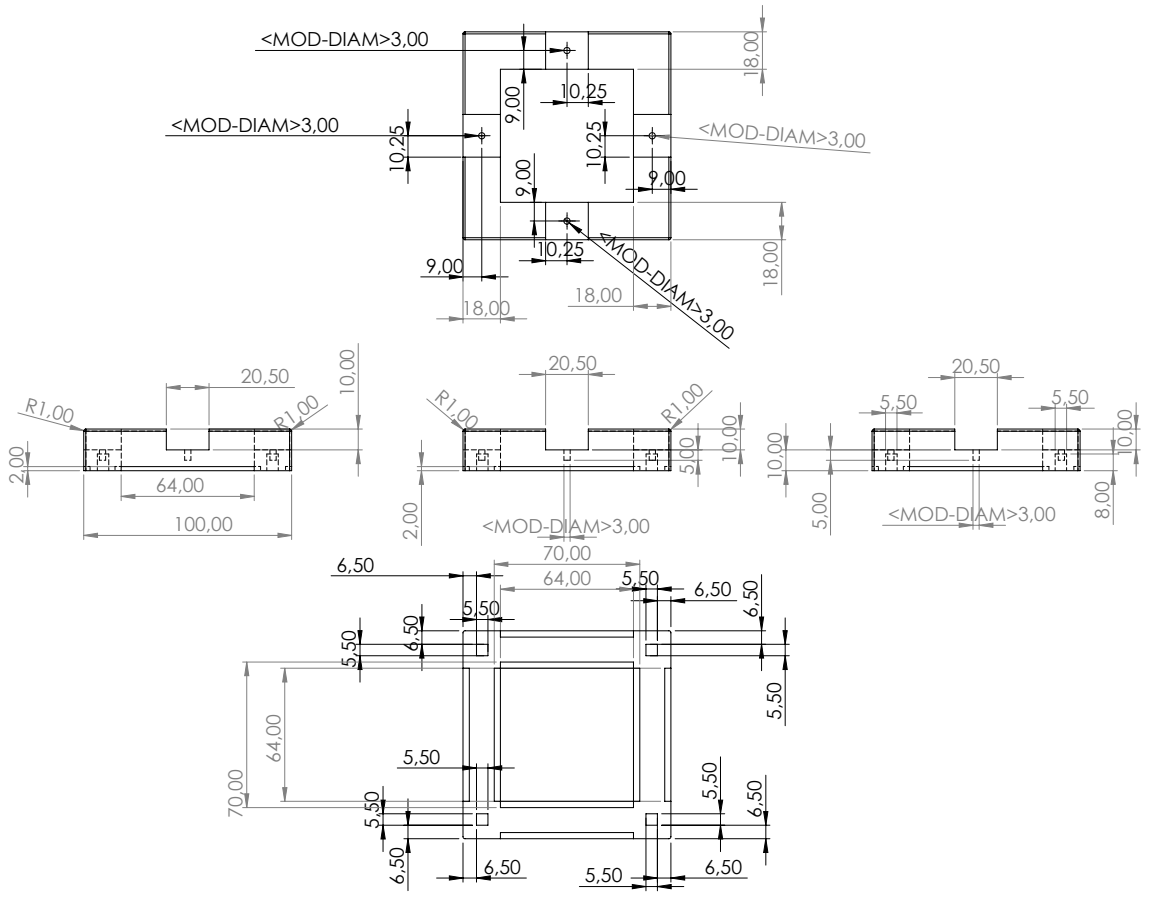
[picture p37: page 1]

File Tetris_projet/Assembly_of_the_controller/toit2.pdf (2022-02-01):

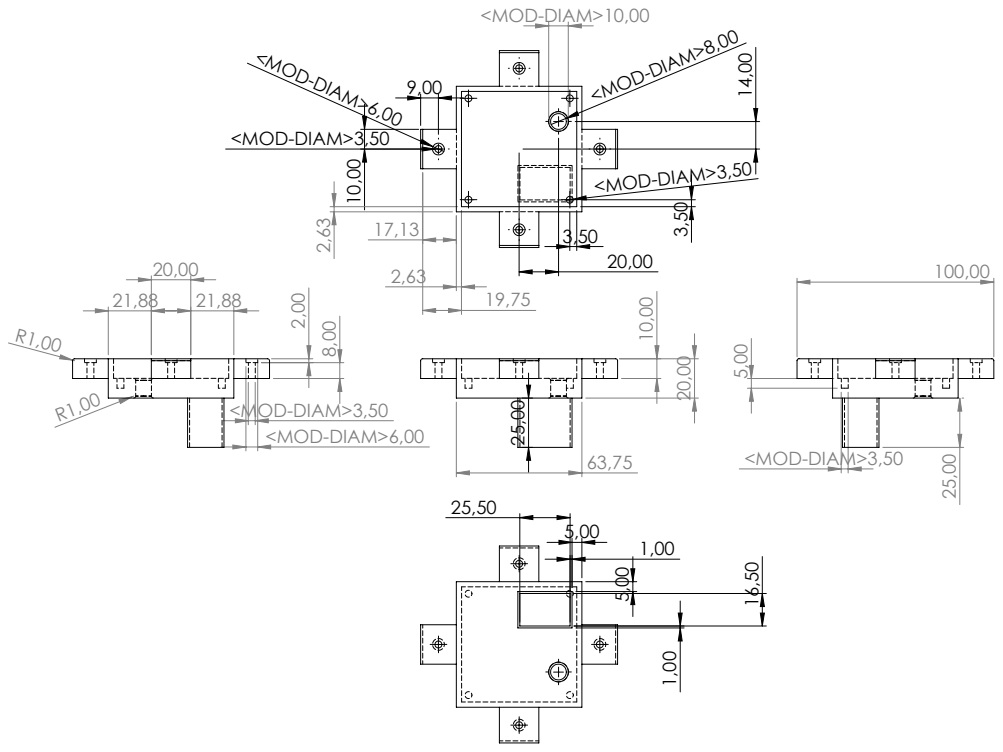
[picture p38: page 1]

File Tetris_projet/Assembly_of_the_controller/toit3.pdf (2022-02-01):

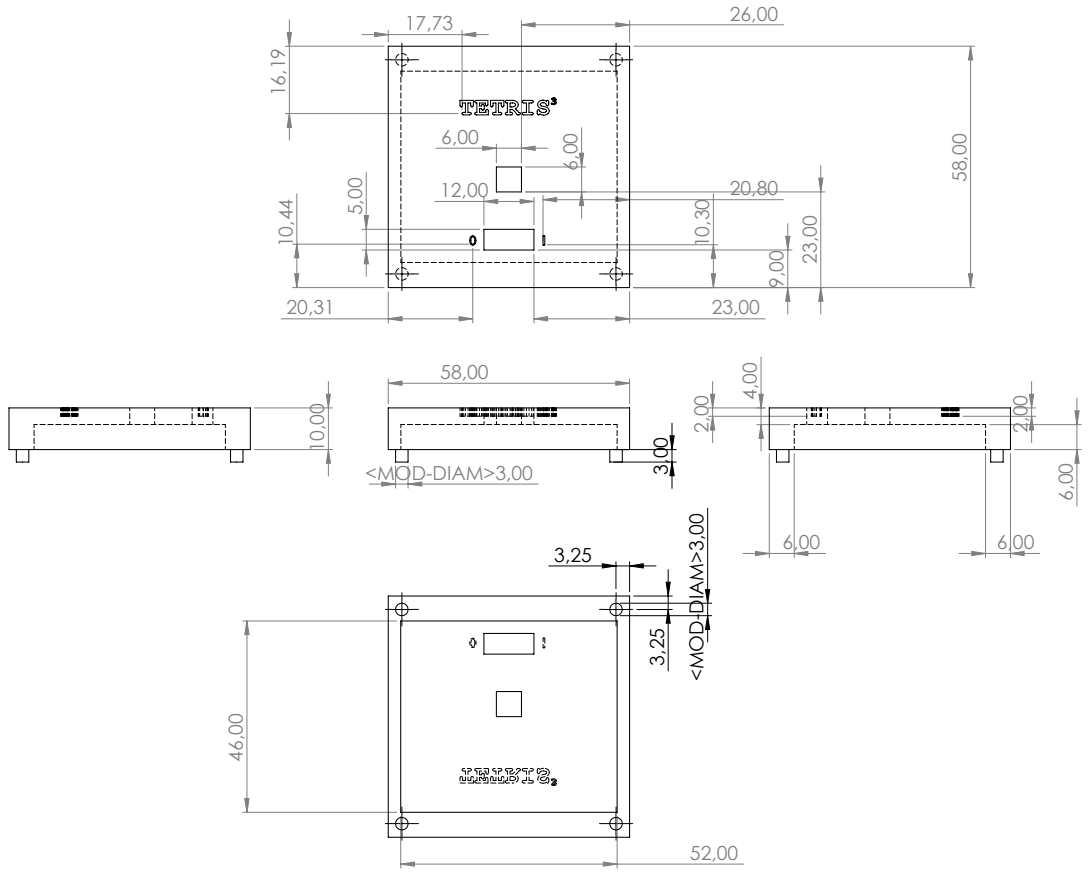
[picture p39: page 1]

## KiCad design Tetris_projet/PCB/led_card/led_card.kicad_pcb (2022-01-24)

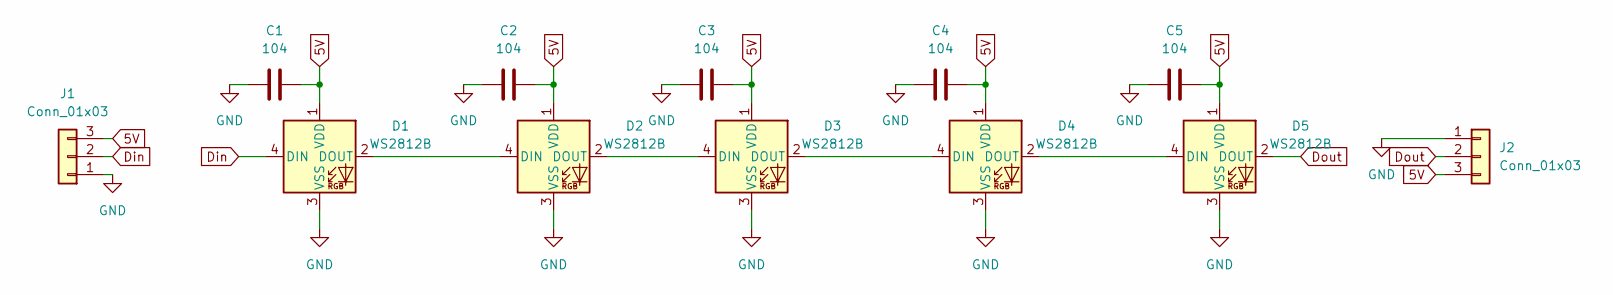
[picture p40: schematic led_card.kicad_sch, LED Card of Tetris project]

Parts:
C1, C2, C3, C4, C5: 104; C_0603_1608Metric_Pad1.08x0.95mm_HandSolder
D1, D2, D3, D4, D5: WS2812B; LED_WS2812B_PLCC4_5.0x5.0mm_P3.2mm
J1, J2: Conn_01x03; PinHeader_1x03_P2.54mm_Vertical

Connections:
5V: C1.1, C2.1, C3.1, C4.1, C5.1, D1.1 (VDD), D2.1 (VDD), D3.1 (VDD), D4.1 (VDD), D5.1 (VDD), J1.3, J2.3
Din: D1.4 (DIN), J1.2
Dout: D5.2 (DOUT), J2.2
GND: C1.2, C2.2, C3.2, C4.2, C5.2, D1.3 (VSS), D2.3 (VSS), D3.3 (VSS), D4.3 (VSS), D5.3 (VSS), J1.1, J2.1
unnamed: D1.2 (DOUT), D2.4 (DIN)
unnamed: D2.2 (DOUT), D3.4 (DIN)
unnamed: D3.2 (DOUT), D4.4 (DIN)
unnamed: D4.2 (DOUT), D5.4 (DIN)

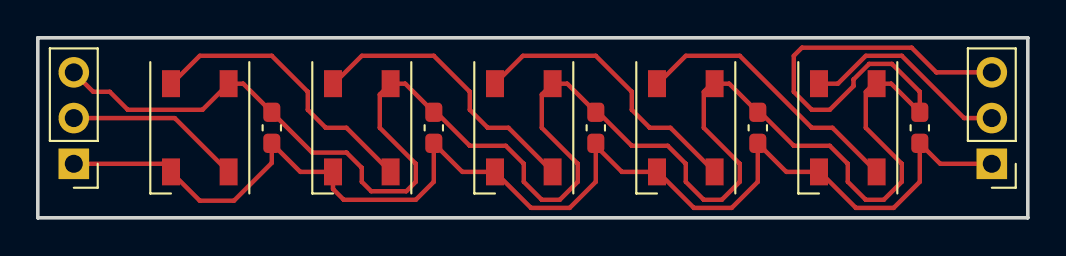
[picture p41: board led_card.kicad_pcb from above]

Board: 2 copper layers, 55.0 x 10.0 mm, 12 parts (0 on the bottom side), 8 nets.

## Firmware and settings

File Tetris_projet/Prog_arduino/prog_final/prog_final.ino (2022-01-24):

  /* LEDs */

#include <FastLED.h>

  /* LED battery */

#define LED_PIN_1     6
#define NUM_LEDS_1    1

  /* LED cube */

#define LED_PIN_2    7
#define NUM_LEDS_2   60

  /* Bluetooth */
#include <SoftwareSerial.h>
#define rxPin 11 // Broche 11 en tant que RX, à raccorder sur TX du HC-05
#define txPin 10 // Broche 10 en tant que TX, à raccorder sur RX du HC-05

  /* Accelero - Gyro */

#include <Wire.h>
#include <MPU6050.h>


/* LED battery */

CRGB leds_1[NUM_LEDS_1];

  /* LED cube */
  
CRGB leds_2[NUM_LEDS_2];

  /* Bluetooth */

SoftwareSerial mySerial(rxPin, txPin);

  /* Accelero - Gyro */
 
MPU6050 mpu;

// accelero left right
int cas;
int Sp = 6;
int Sn =-6;
int idState=0;
bool flag = true;
bool testp, testn;

//gyro
int etat=0;

int Spxh =16000;
int Sph =14000;
int Spb =5000;

int Snxh =-16000;
int Snh=-14000;
int Snb =-5000;

// accelero down
int state=0;

int Sdph = 8;
int Sdpb = 1;




void setup() {
  Serial.begin(115200);

  /* LED battery */
  FastLED.addLeds<WS2812, LED_PIN_1, GRB>(leds_1, NUM_LEDS_1);

  /* LED cube */
  FastLED.addLeds<WS2812, LED_PIN_2, GRB>(leds_2, NUM_LEDS_2);

    /* Bluetooth */

  pinMode(rxPin, INPUT);
  pinMode(txPin, OUTPUT);
  mySerial.begin(9600);

     /* Accelero - Gyro */

  Serial.println("Initialize MPU6050");

  while(!mpu.begin(MPU6050_SCALE_2000DPS, MPU6050_RANGE_2G))
  {
    Serial.println("Could not find a valid MPU6050 sensor, check wiring!");
    delay(500);
  }
    checkSettings();


}

void checkSettings()
{
  Serial.println();
  
  Serial.print(" * Sleep Mode:            ");
  Serial.println(mpu.getSleepEnabled() ? "Enabled" : "Disabled");
  
  Serial.print(" * Clock Source:          ");
  switch(mpu.getClockSource())
  {
    case MPU6050_CLOCK_KEEP_RESET:     Serial.println("Stops the clock and keeps the timing generator in reset"); break;
    case MPU6050_CLOCK_EXTERNAL_19MHZ: Serial.println("PLL with external 19.2MHz reference"); break;
    case MPU6050_CLOCK_EXTERNAL_32KHZ: Serial.println("PLL with external 32.768kHz reference"); break;
    case MPU6050_CLOCK_PLL_ZGYRO:      Serial.println("PLL with Z axis gyroscope reference"); break;
    case MPU6050_CLOCK_PLL_YGYRO:      Serial.println("PLL with Y axis gyroscope reference"); break;
    case MPU6050_CLOCK_PLL_XGYRO:      Serial.println("PLL with X axis gyroscope reference"); break;
    case MPU6050_CLOCK_INTERNAL_8MHZ:  Serial.println("Internal 8MHz oscillator"); break;
  }
  
  Serial.print(" * Accelerometer:         ");
  switch(mpu.getRange())
  {
    case MPU6050_RANGE_16G:            Serial.println("+/- 16 g"); break;
    case MPU6050_RANGE_8G:             Serial.println("+/- 8 g"); break;
    case MPU6050_RANGE_4G:             Serial.println("+/- 4 g"); break;
    case MPU6050_RANGE_2G:             Serial.println("+/- 2 g"); break;
  }  

  Serial.print(" * Accelerometer offsets: ");
  Serial.print(mpu.getAccelOffsetX());
  Serial.print(" / ");
  Serial.print(mpu.getAccelOffsetY());
  Serial.print(" / ");
  Serial.println(mpu.getAccelOffsetZ());
  
  Serial.println();
}

void loop() {
  
  /* LED Battery */
  
  int resultBinary = analogRead(A0);
  float resultVolts = resultBinary / 1023.0 * 5.0;
  int R1 = 100;
  int R2 = 220;
  float tension = (resultVolts / R1 * (R1 + R2))-0.5;

  float pourc_volt = (tension/9.80)*100;
  
  if (pourc_volt > 80){
    leds_1[0] = CRGB(0, 4, 4);
    FastLED.show();
  }
  if ((pourc_volt>60) && (pourc_volt<80)){
    leds_1[0] = CRGB(0, 4, 0);
    FastLED.show(); 
  }
  if ((pourc_volt>40) && (pourc_volt<60)){
    leds_1[0] = CRGB(4, 4, 0);
    FastLED.show(); 
  }
  if ((pourc_volt>20) && (pourc_volt<40)){
    leds_1[0] = CRGB(4, 1, 0);
    FastLED.show(); 
  }
  if (pourc_volt<20){
    leds_1[0] = CRGB(4, 0, 0);
    FastLED.show();
  }  

  /* LED cube */

  int i=0;
  while (i<13){
    leds_2[i] = CRGB(0, 0, 255);
    leds_2[i+12] = CRGB(0, 0, 255);
    leds_2[i+24] = CRGB(0, 0, 255);
    leds_2[i+36] = CRGB(0, 0, 255);
    leds_2[i+48] = CRGB(0, 0, 255);
    if(i>0){
          leds_2[i-1]=CRGB(0, 0, 0);
          leds_2[i+11]=CRGB(0, 0, 0);
          leds_2[i+23]=CRGB(0, 0, 0);
          leds_2[i+35]=CRGB(0, 0, 0);
          leds_2[i+47]=CRGB(0, 0, 0);
    }
    FastLED.show();
    i++;

    /* Mouvements */

    Vector rawAccel = mpu.readRawAccel();
  Vector normAccel = mpu.readNormalizeAccel();

  /*if(normAccel.ZAxis > 18){
    cas = 1;
  }
  else if(normAccel.YAxis < -7){
    cas= 2;
  }*/

  if(normAccel.XAxis >= Sp){
    testp = true;
  }
  else{
    testp=false;
  }
  if(normAccel.XAxis <= Sn){
    testn = true;
  }
  else{
    testn=false;
  }

  if (idState==0){
    if(testp==true){
      idState=1;
      cas=3;
    }
    else if(testn==true){
      idState=3;
      cas=4;
    }
  }
  else if(idState==1){
    if(testn==true){
      idState=2;
    }
  }
  else if(idState==2){
    if(testn == false){
      idState=0;
    }
  }
  if(idState==0){
    if(testp==true){
      idState=1;
      cas=3;
    }
  }
  else if(idState==1){
    if(testn==true){
      idState==2;
    }
  }
  else if(idState==2){
    if (testn==false){
      idState=0;
    }
  }
  else if(idState==3){
    if (testp==true){
      idState=4;
    }
  }
  else if(idState==4){
    if (testp==false){
      idState=0;
    }
  }


  //gyro

  if(etat==0){
    if((rawAccel.XAxis <= Spxh)&&(rawAccel.XAxis >= Sph)){
      etat=1;
      cas = 5;
    }
    else if((rawAccel.XAxis >= Snxh)&& (rawAccel.XAxis <= Snh)){
      etat = -1;
      cas = 6;
    }
  }
  else if(etat==1){
    etat=2;
  }
  else if(etat==2){
    if(rawAccel.XAxis <= Spb){
      etat=0;
    }
  }
  else if(etat==-1){
    etat=-2;
  }
  else if(etat==-2){
    if(rawAccel.XAxis >= Snb){
      etat=0;
    }
  }

  //down

  if(state==0){
    if(normAccel.ZAxis <= Sdpb){
      state=1;
      cas=1;
    }
  }
  else if(state==1){
    state=2;
  }
  else if(state==2){
    if(normAccel.ZAxis>=Sdph){
      state=0;
    }
  }

  
  switch(cas){
    case 0:
      break;
    case 1:
      Serial.println("bas");
      mySerial.println("bas");
      break;
    /*case 2:
      Serial.println("pause");
      break;*/
    case 3:
      Serial.println("droite");
      mySerial.println("droite");
      break;
    case 4:
      Serial.println("gauche");
      mySerial.println("gauche");
      break;
    case 5:
      Serial.println("rot left");
      mySerial.println("rotleft");
      break;
    case 6:
      Serial.println("rot right");
      mySerial.println("rotright");
      break;    
   }
   cas=0;

    
    delay(42);  
  }
}

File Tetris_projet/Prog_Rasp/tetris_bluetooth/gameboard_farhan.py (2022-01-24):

import pygame
import random
#BLACK = (0, 0, 0)
#WHITE = (255, 255, 255)
# RED = (255, 0, 0)
# GREEN = (0, 255, 0)
#BLUE = (0, 0, 255)
# ORANGE = (255, 128, 0)
# YELLOW = (255, 255, 0)
# PINK = (255, 0, 127)

BLACK = (40, 42, 54)
WHITE = (248, 248, 242)
RED = (255, 85, 85)
GREEN = (80, 250, 123)
BLUE = (139, 233, 253)
BBLUE = (98, 114, 164)
ORANGE = (255, 184, 108)
YELLOW = (241, 250, 140)
PINK = (255, 121, 198)
GREY = (68, 71, 90)
NBLEU = (0, 128 ,255)

AllColours = [BLUE, BLUE, BLUE, BLUE, WHITE, WHITE, WHITE, WHITE]
pygame.init()
linesound = pygame.mixer.Sound('clearline.wav')
#line = pygame.mixer.Sound('ligne.mp3')
#yahoo = pygame.mixer.Sound('yeahoo.mp3')
#wow = pygame.mixer.Sound('wow.mp3')
#wow2 = pygame.mixer.Sound('wow_2.mp3')
#applause = pygame.mixer.Sound('applause.mp3')
pygame.mixer.music.set_volume(2)
gameboard_width = 12
gameboard_height = 20
activeBoardSpot = [[0 for y in range(gameboard_height)] for x in range(gameboard_width)]
activeBoardColour = [[0 for y in range(gameboard_height)] for x in range(gameboard_width)]

class Gameboard():
    def __init__(self, colour, blocksize):
        self.colour = colour
        self.multiplier = blocksize
        self.score = 0
        self.lines = 0
        self.tempTracker = 0
        self.levelTracker = 1
        self.numslowtime = 0
        self.numslowtimeon = False
        self.numswap = 0
        self.swapshape = False
        self.linescounter = 0
        self.shakescreen = False
        for i in range(gameboard_width):
            for j in range(gameboard_height):
                activeBoardSpot[i][j] = False
                activeBoardColour[i][j] = BLACK

    def draw(self, screen):
        pygame.draw.rect(screen, GREY, [0, 0, gameboard_width * self.multiplier, gameboard_height * self.multiplier], 0)
        for i in range(gameboard_width):
            for j in range(gameboard_height):
                if activeBoardSpot[i][j]:
                    pygame.draw.rect(screen, activeBoardColour[i][j], [i * self.multiplier, j * self.multiplier, self.multiplier -1, self.multiplier -1], 0)



    def checkLoss(self):
        for i in range(gameboard_width):
            if activeBoardSpot[i][0]:
                return True
        return False

    def isCompleteLine(self, rownum):
        for i in range(gameboard_width):
            if activeBoardSpot[i][rownum] == False:
                return False
        return True
    def drawshake(self, screen):
        normalwidth = gameboard_width * self.multiplier
        normalheight = gameboard_height * self.multiplier
        shakeamount = 10
        shakecounter = 0
        while self.shakescreen:
            pygame.draw.rect(screen, GREY,[0, 0, normalwidth+ shakeamount, normalheight + shakeamount], 5)
            for i in range(gameboard_width):
                for j in range(gameboard_height):
                    Colour = AllColours[random.randrange(7)]
                    pygame.draw.rect(screen, Colour, [i * self.multiplier, j *self.multiplier, self.multiplier -1, self.multiplier -1], 0)
            pygame.display.flip()
            if shakeamount%5 == 0:
                if shakeamount == 10:
                    shakeamount = -shakeamount

            if shakecounter > 100:
                self.shakescreen = False

            shakecounter += 1
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

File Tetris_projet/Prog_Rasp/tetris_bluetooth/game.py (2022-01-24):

#########################################################
# INSPIRED BY FARHAN TETRIS PROGRAM #
#########################################################


# getting function from library
import pygame
import time
import os

from pygame.constants import FULLSCREEN
from Block_farhan import Block
from shape_farhan import Shape
from gameboard_farhan import *
import sys

from pynput.keyboard import Key, Controller

keyboard = Controller()

cmd2='python3 blu_key.py &'
os.system(cmd2)
    
# colours
#BLACK = (0, 0, 0)
#WHITE = (255, 255, 255)
#RED = (255, 0, 0)
#GREEN = (0, 255, 0)
#BLUE = (0, 0, 255)
#ORANGE = (255, 128, 0)
#YELLOW = (255, 255, 0)
#PINK = (255, 0, 127)

BLACK = (40, 42, 54)
WHITE = (255, 255, 255)
RED = (255, 85, 85)
GREEN = (80, 250, 123)
BBLUE = (98, 114, 164)
BLUE = (139, 233, 253)
ORANGE = (255, 184, 108)
YELLOW = (241, 250, 140)
PINK = (255, 121, 198)
NBLEU = (0, 128, 255)
PURPLE = (189, 147, 249)


if __name__ == "__main__":
# initalize the game engine
    
    pygame.init()
    
    started = False
    # playing music
    pygame.mixer.init()
    pygame.mixer.music.load('tetris_trance.mp3')
    pygame.mixer.music.play(-1)
    pygame.mixer.music.set_volume(0.05)
# making window
    size = (800, 600)
    screen = pygame.display.set_mode(size)
    #screen = pygame.display.set_mode((800,600), pygame.FULLSCREEN,32)
# setting caption
    pygame.display.set_caption('TETRIS^3')
    shape = Shape()
    nextshape = Shape()
    gameboard = Gameboard(WHITE, 25)
    done = False
    delay = 0
    score = 0
    myfont = pygame.font.SysFont('Early GameBoy', 20)     # modification police interface
    myfont1 = pygame.font.SysFont('Fira Mono', 50)  # modification police nom du joueur
    myfont3 = pygame.font.SysFont('Early GameBoy', 100)
    slowtimedelay = 0
    leftKey = False
    rightKey = False
    downKey = False
    name = ""
    namelist = [0 for i in range(5)]
    scorelist = [0 for y in range(5)]
    HSFile = open("highscores.txt", "r")
    for i in range(5):
        namelist[i] = HSFile.readline().rstrip("\n")
    for y in range(5):
        scorelist[y] = HSFile.readline().rstrip('\n')
    HSFile.close()
    paused = False
    holding = False
    changehold = False
    holdshape = None


def checkhighscores():
    newHS = False
    tempnamelist = [0 for y in range(5)]
    tempscorelist = [0 for y in range(5)]
    for i in range(5):
        if gameboard.score > int(scorelist[i]) and newHS == False:
            newHS = True
            tempscorelist[i] = gameboard.score
            tempnamelist[i] = name
        elif newHS == True:
            tempscorelist[i] = scorelist[i -1]
            tempnamelist[i] = namelist[i -1]
        else:
            tempscorelist[i] = scorelist[i]
            tempnamelist[i] = namelist[i]

    for i in range(5):
        scorelist[i] = tempscorelist[i]
        namelist[i] = tempnamelist[i]

    HSFile = open("highscores.txt", "w")

    for i in range(5):
        HSFile.write(str(namelist[i]) + "\n")
    for i in range(5):
        HSFile.write(str(scorelist[i]) + "\n")
    HSFile.close()

def Drawscreen():
    screen.fill(BBLUE)

    if gameboard.shakescreen:
        gameboard.drawshake(screen)
    else:
        gameboard.draw(screen)

    shape.drawShadow(screen)
    shape.draw(screen)

    scoreText = myfont.render('S C O R E : ' + str(gameboard.score), True, BLUE)
    screen.blit(scoreText, (330, 400))
    linesText = myfont.render('L I N E S : ' + str(gameboard.lines), True, BLUE)
    screen.blit(linesText, (330, 350))
    LevelText = myfont.render('S P E E D  x ' + str(gameboard.levelTracker), True, BLUE)
    screen.blit(LevelText, (330, 300))
    nextshapetext = myfont.render('N E X T : ', True, BLUE)
    pygame.draw.rect(screen, WHITE, [330, 100, 6 * shape.blocklist[0].size, 6 * shape.blocklist[0].size], 1)
    screen.blit(nextshapetext, (330, 50))
    nextshape.drawNewShape(screen)
    #poweruptext = myfont.render("P O W E R U P S : ", True, PINK)
    #screen.blit(poweruptext, (50, 525))
    #numslowtimestext = myfont.render(" X   " + str(gameboard.numslowtime), True, PINK)
    #screen.blit(numslowtimestext, (310, 525))
    #slowtime_image = pygame.image.load('clock.png')
    #screen.blit(slowtime_image, (250, 515))
    #numswaptext = myfont.render('   X ' + str(gameboard.numswap), True, PINK)
    #screen.blit(numswaptext, (435, 525))
    #swap_image = pygame.image.load("swap.png")
    #screen.blit(swap_image, (375, 515))
    highscoretext = myfont.render("H I G H S C O R E S : ", True, BLUE)
    screen.blit(highscoretext, (575, 50))
    pygame.draw.rect(screen, WHITE, [575, 100, 200, 400], True)
    playernametext = myfont1.render(name, True, BLUE)
    screen.blit(playernametext,(600, 525))
    for i in range(5):
        highscoreplayertext = myfont.render(str(namelist[i]) + "        " + str(scorelist[i]), True, BLUE)
        screen.blit(highscoreplayertext, (600, 100 + 30 * i))
    pygame.display.flip()

def keypressed():
#     
    if event.key == pygame.K_LEFT :
        shape.MoveLeft()
    elif event.key == pygame.K_RIGHT :
        shape.MoveRight()
    elif event.key == ord('d'):
        global downKey
        downKey = True
    elif event.key == pygame.K_UP or event.key == ord('w'):
        shape.RotateCW() # tourne la piece dans le sens des aiguilles d'une montre
    elif event.key == pygame.K_DOWN or event.key == ord('s'):
        shape.RotateCCW() # tourne la piece dans le sens inverse des aiguilles d'une montre
    elif event.key == pygame.K_SPACE or event.key == ord('h') :
        gameboard.score += (gameboard_height - shape.blocklist[0].gridy)
        shape.fall()
    elif event.key == ord('t') and gameboard.numslowtime > 0:
        gameboard.numslowtimeon = True
        gameboard.numslowtime -= 1
    elif event.key == ord('f') and gameboard.numswap > 0:
        gameboard.swapshape = True
        gameboard.numswap -= 1
    elif event.key == ord('p'):
        global paused
        paused = True
    elif event.key == ord('p'):
        paused = False


def keyReleased():
    if event.key == pygame.K_d:
        global downKey
        downKey = False


def keycheck():
    
    if downKey:
        shape.MoveDown()
    




while not started:  # Title screen
    titlescreen = pygame.image.load('background1.png')
    nametext = myfont.render(name, True, WHITE)
    screen.blit(titlescreen, (0, 0))
    pygame.display.flip()
    for event in pygame.event.get():
        if event.type == pygame.QUIT:
            done = True
            started = True
        if event.type == pygame.KEYDOWN:
            if event.key >= 33 and event.key <= 126 and len(name) < 10:
                name += chr(event.key)
            if event.key == pygame.K_BACKSPACE:
                name = name[: - 1]
            if event.key == pygame.K_RETURN:
                if name == "":
                    name = "Player"
                started = True
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
